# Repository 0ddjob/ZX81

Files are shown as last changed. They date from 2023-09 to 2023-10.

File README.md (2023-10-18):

# ZX81 Projects

## [ZX81 RAM Upgrade](RAM_Upgrade)
Simple plug-in 32KB RAM for ZX81 &amp; TS1000 using through-hole SRAM.  Expectation is that it's used with the very excellent [vLA81](https://www.vretrodesign.com/products/vla81-zx81-ula-replacement).<br>

{Fri 15-Sept-2023}<br>
Sent board prototype for fabrication<br>

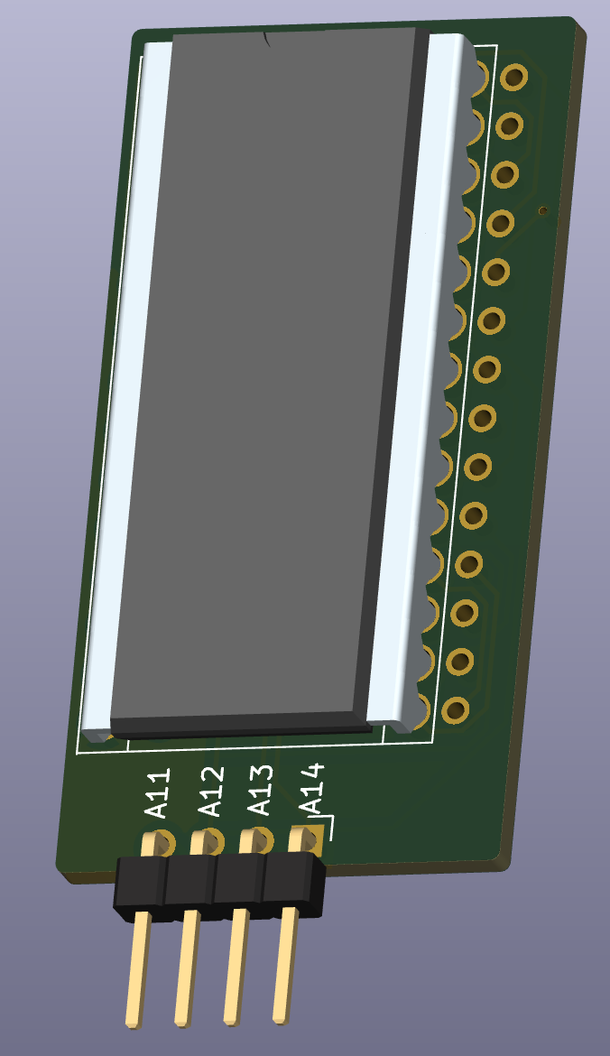
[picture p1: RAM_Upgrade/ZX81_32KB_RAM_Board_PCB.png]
PCB


## [ZX81 Centronics Interface](Centronics)
Redrawn from the original c't magazine schematic.<br>
{Sat 16-Sept-2023}<br>
Work in progress

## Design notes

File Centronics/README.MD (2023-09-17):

# ZX81 Centronics Interface

Recreating a DIY centronics interface from German computer magazine c't.<br>

Google [auto-translation](ZX81_Centronics_Interface_p1.jpg) of the German.

[Redrawn schematic](ZX81_Centronics.pdf)

{17-Sept-2023}:<br>
Work in progress ... <br>
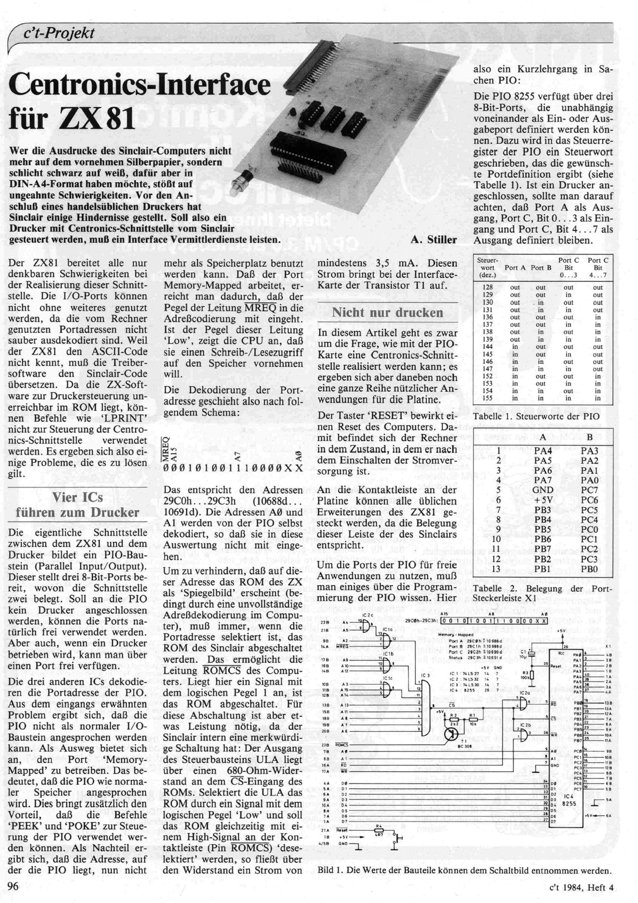
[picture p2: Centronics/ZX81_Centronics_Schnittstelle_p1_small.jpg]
CT_mag1


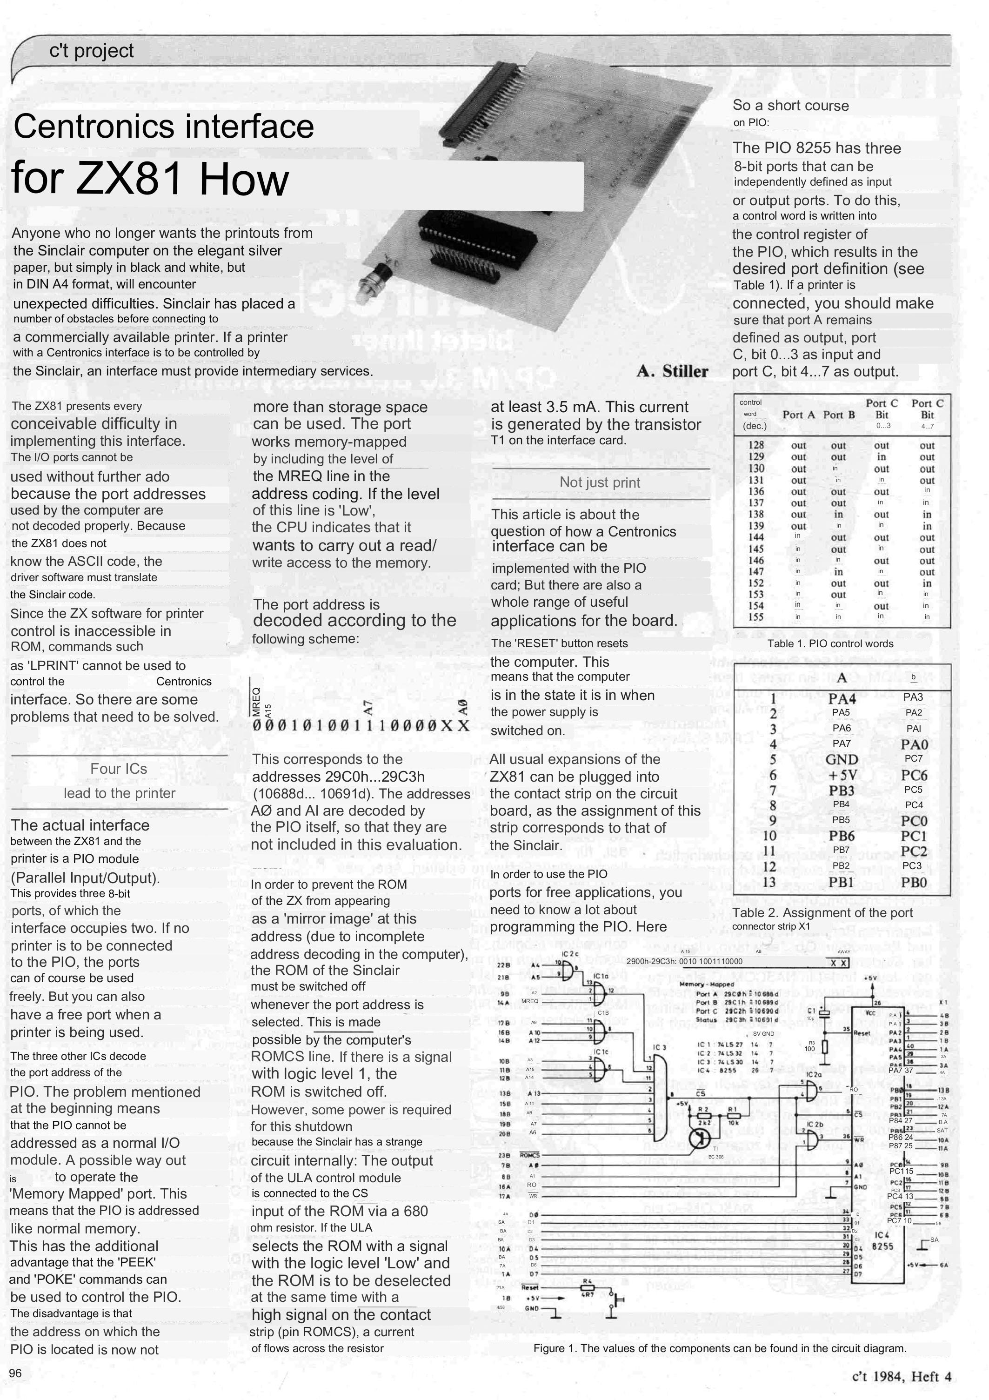
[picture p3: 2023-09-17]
Centronics/ZX81_Centronics_Interface_p1.jpg

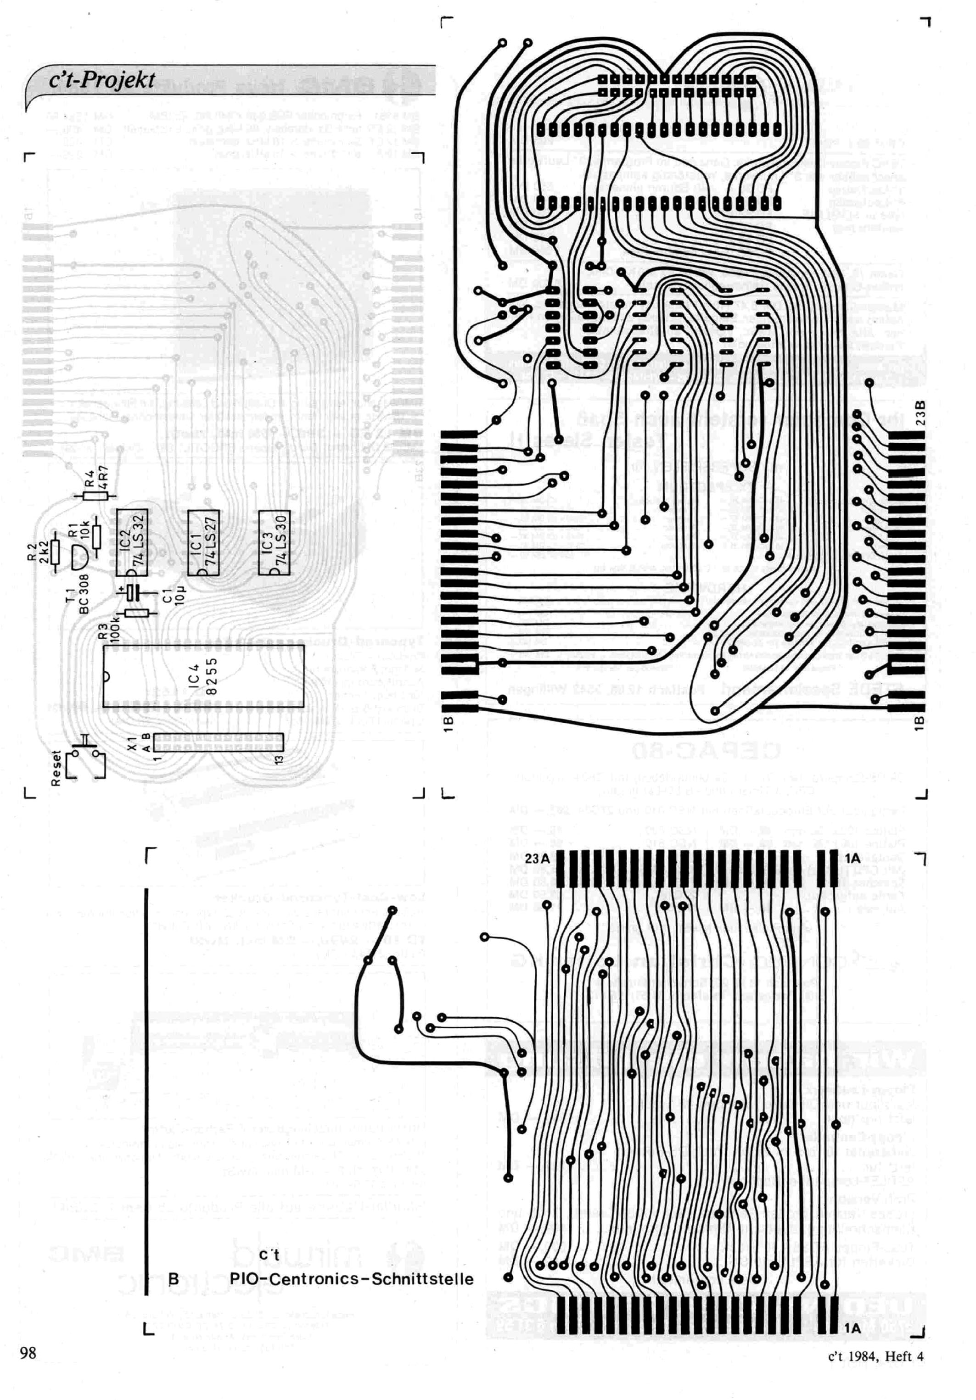
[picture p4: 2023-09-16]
Centronics/ZX81_Centronics_Schnittstelle_p2.jpg

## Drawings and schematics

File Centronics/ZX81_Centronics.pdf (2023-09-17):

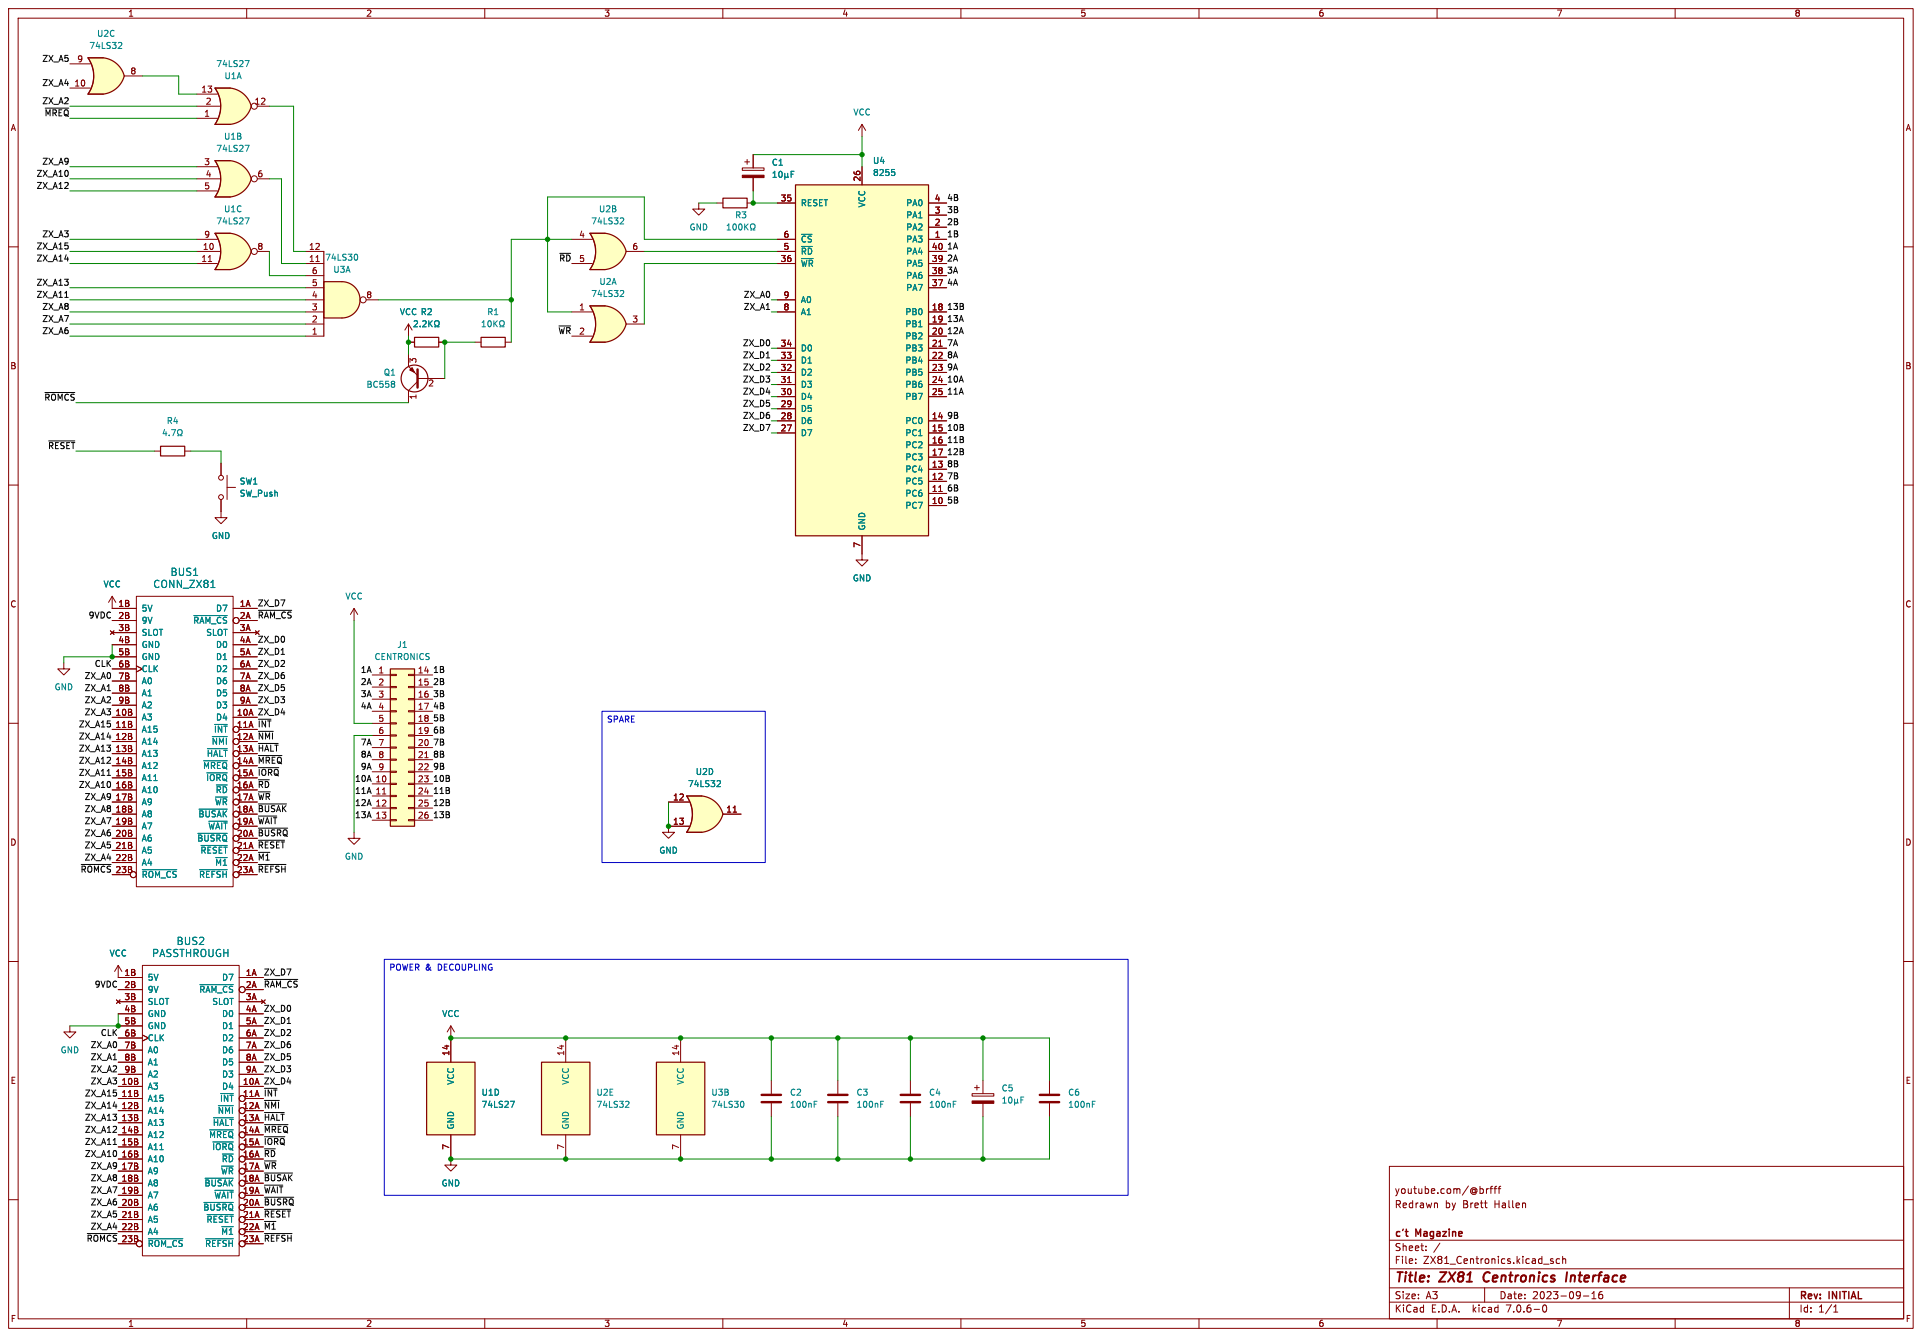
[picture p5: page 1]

ZX_D2 ZX_D1 ZX_D6 ZX_D4 ~{IORQ} ~{RD} ~{WR} ~{HALT} ~{MREQ} ~{INT} ~{M1} ~{BUSRQ} ~{WAIT} ~{REFSH} ~{BUSAK} ~{RESET} ZX_D5

File: ZX81_Centronics.kicad_sch Sheet: / c't Magazine Redrawn by Brett Hallen

Id: 1/1 Title: ZX81 Centronics Interface

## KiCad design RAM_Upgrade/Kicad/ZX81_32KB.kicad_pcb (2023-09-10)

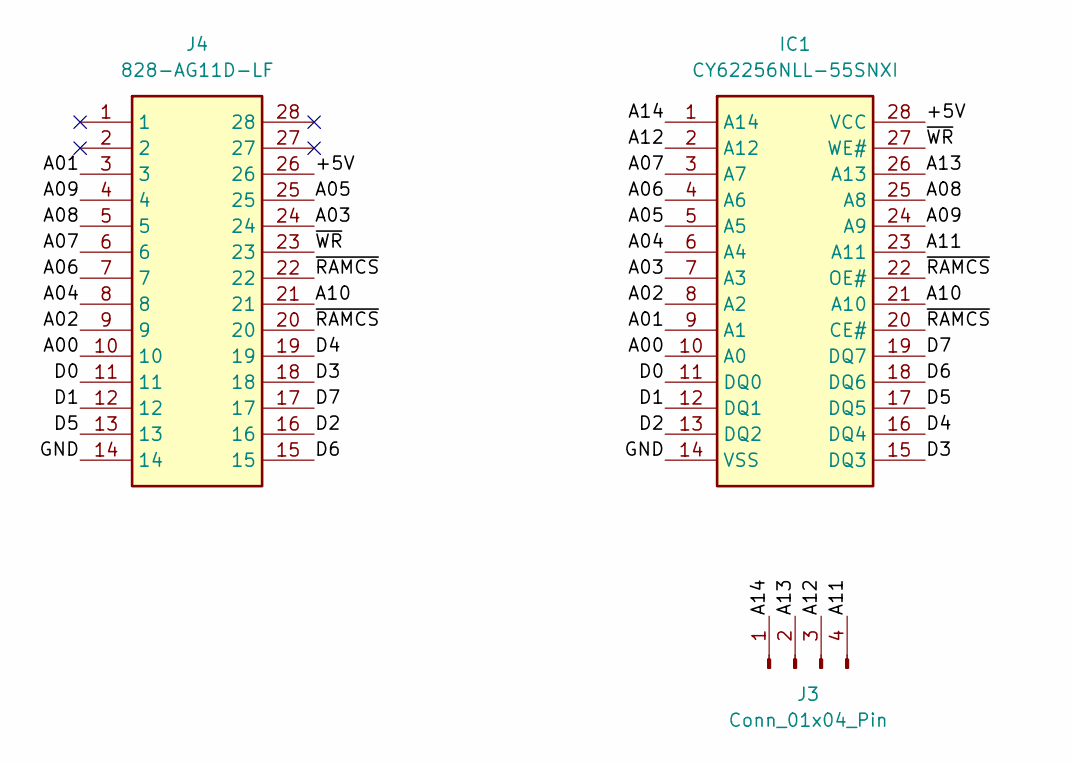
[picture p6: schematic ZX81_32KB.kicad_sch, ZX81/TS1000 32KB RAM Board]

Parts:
IC1: CY62256NLL-55SNXI; DIP1587W140P254L3632H381Q28N; Mouser Part Number 913-AS6C62256-55PCN
J3: Conn_01x04_Pin; PinHeader_1x04_P2.54mm_Horizontal
J4: 828-AG11D-LF; 828AG11DLF; Mouser Part Number 571-2-1571586-9

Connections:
/+5V: IC1.28 (VCC), J4.26
/A00: IC1.10 (A0), J4.10
/A01: IC1.9 (A1), J4.3
/A02: IC1.8 (A2), J4.9
/A03: IC1.7 (A3), J4.24
/A04: IC1.6 (A4), J4.8
/A05: IC1.5 (A5), J4.25
/A06: IC1.4 (A6), J4.7
/A07: IC1.3 (A7), J4.6
/A08: IC1.25 (A8), J4.5
/A09: IC1.24 (A9), J4.4
/A10: IC1.21 (A10), J4.21
/A11: IC1.23 (A11), J3.4
/A12: IC1.2 (A12), J3.3
/A13: IC1.26 (A13), J3.2
/A14: IC1.1 (A14), J3.1
/D0: IC1.11 (DQ0), J4.11
/D1: IC1.12 (DQ1), J4.12
/D2: IC1.13 (DQ2), J4.16
/D3: IC1.15 (DQ3), J4.18
/D4: IC1.16 (DQ4), J4.19
/D5: IC1.17 (DQ5), J4.13
/D6: IC1.18 (DQ6), J4.15
/D7: IC1.19 (DQ7), J4.17
/GND: IC1.14 (VSS), J4.14
/~RAMCS: IC1.20 (CE#), IC1.22 (OE#), J4.20, J4.22
/~WR: IC1.27 (WE#), J4.23

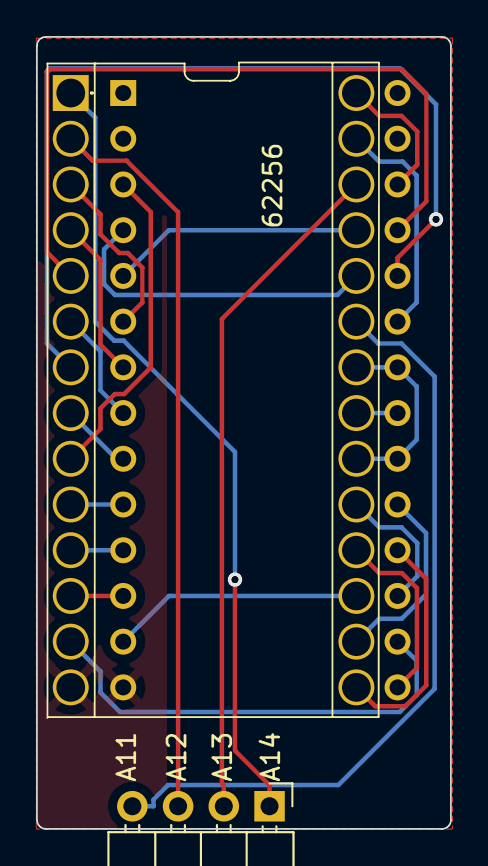
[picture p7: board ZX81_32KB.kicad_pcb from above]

Board: 2 copper layers, 23.0 x 44.0 mm, 3 parts (0 on the bottom side), 27 nets.

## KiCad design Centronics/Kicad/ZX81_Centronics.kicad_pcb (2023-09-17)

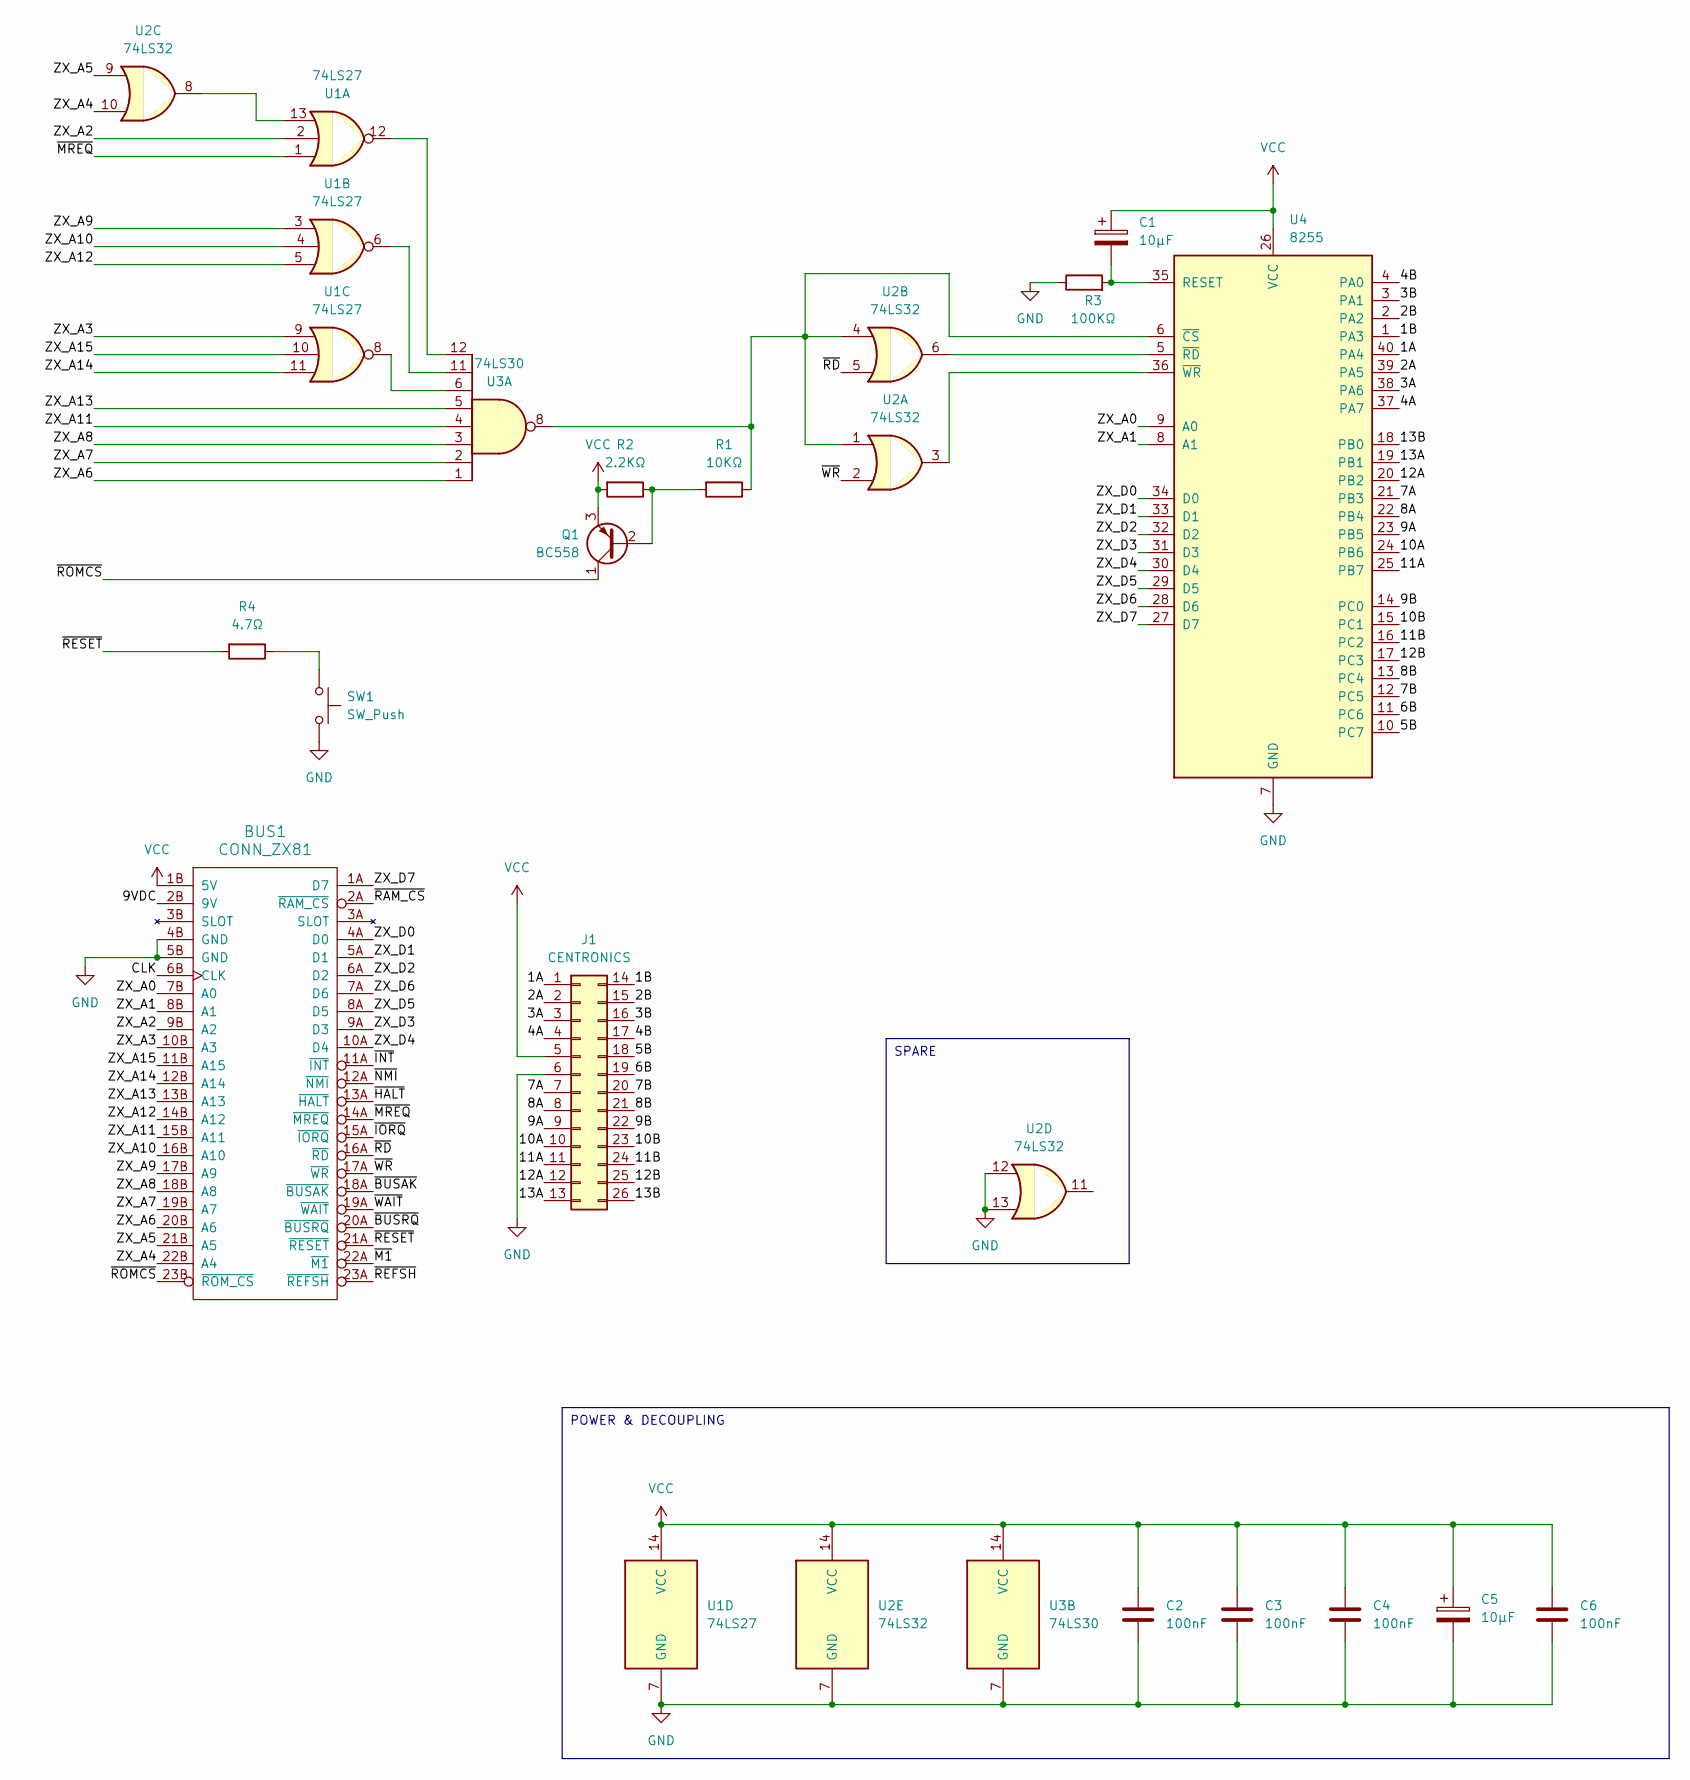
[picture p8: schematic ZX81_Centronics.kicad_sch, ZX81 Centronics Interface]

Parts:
BUS1: CONN_ZX81; ZX81_EDGE
C1, C5: 10µF; CP_Radial_D5.0mm_P2.50mm
C2, C3, C4, C6: 100nF; C_Disc_D4.3mm_W1.9mm_P5.00mm
J1: CENTRONICS; PinHeader_2x13_P2.54mm_Vertical
Q1: BC558; TO-92_Inline
R1: 10KΩ; R_Axial_DIN0207_L6.3mm_D2.5mm_P7.62mm_Horizontal
R2: 2.2KΩ; R_Axial_DIN0207_L6.3mm_D2.5mm_P7.62mm_Horizontal
R3: 100KΩ; R_Axial_DIN0207_L6.3mm_D2.5mm_P7.62mm_Horizontal
R4: 4.7Ω; R_Axial_DIN0207_L6.3mm_D2.5mm_P7.62mm_Horizontal
SW1: SW_Push; SW_PUSH_6mm_H4.3mm
U1: 74LS27; DIP-14_W7.62mm
U2: 74LS32; DIP-14_W7.62mm
U3: 74LS30; DIP-14_W7.62mm
U4: 8255; DIP-40_W15.24mm

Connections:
/1A: J1.1, U4.40 (PA4)
/1B: J1.14, U4.1 (PA3)
/2A: J1.2, U4.39 (PA5)
/2B: J1.15, U4.2 (PA2)
/3A: J1.3, U4.38 (PA6)
/3B: J1.16, U4.3 (PA1)
/4A: J1.4, U4.37 (PA7)
/4B: J1.17, U4.4 (PA0)
/5B: J1.18, U4.10 (PC7)
/6B: J1.19, U4.11 (PC6)
/7A: J1.7, U4.21 (PB3)
/7B: J1.20, U4.12 (PC5)
/8A: J1.8, U4.22 (PB4)
/8B: J1.21, U4.13 (PC4)
/9A: J1.9, U4.23 (PB5)
/9B: J1.22, U4.14 (PC0)
/9VDC: BUS1.2B (9V)
/10A: J1.10, U4.24 (PB6)
/10B: J1.23, U4.15 (PC1)
/11A: J1.11, U4.25 (PB7)
/11B: J1.24, U4.16 (PC2)
/12A: J1.12, U4.20 (PB2)
/12B: J1.25, U4.17 (PC3)
/13A: J1.13, U4.19 (PB1)
/13B: J1.26, U4.18 (PB0)
/CLK: BUS1.6B (CLK)
/ZX_A0: BUS1.7B (A0), U4.9 (A0)
/ZX_A1: BUS1.8B (A1), U4.8 (A1)
/ZX_A2: BUS1.9B (A2), U1.2
/ZX_A3: BUS1.10B (A3), U1.9
/ZX_A4: BUS1.22B (A4), U2.10
/ZX_A5: BUS1.21B (A5), U2.9
/ZX_A6: BUS1.20B (A6), U3.1
/ZX_A7: BUS1.19B (A7), U3.2
/ZX_A8: BUS1.18B (A8), U3.3
/ZX_A9: BUS1.17B (A9), U1.3
/ZX_A10: BUS1.16B (A10), U1.4
/ZX_A11: BUS1.15B (A11), U3.4
/ZX_A12: BUS1.14B (A12), U1.5
/ZX_A13: BUS1.13B (A13), U3.5
/ZX_A14: BUS1.12B (A14), U1.11
/ZX_A15: BUS1.11B (A15), U1.10
/ZX_D0: BUS1.4A (D0), U4.34 (D0)
/ZX_D1: BUS1.5A (D1), U4.33 (D1)
/ZX_D2: BUS1.6A (D2), U4.32 (D2)
/ZX_D3: BUS1.9A (D3), U4.31 (D3)
/ZX_D4: BUS1.10A (D4), U4.30 (D4)
/ZX_D5: BUS1.8A (D5), U4.29 (D5)
/ZX_D6: BUS1.7A (D6), U4.28 (D6)
/ZX_D7: BUS1.1A (D7), U4.27 (D7)
/~BUSAK: BUS1.18A (~BUSAK)
/~BUSRQ: BUS1.20A (~BUSRQ)
/~HALT: BUS1.13A (~HALT)
/~INT: BUS1.11A (~INT)
/~IORQ: BUS1.15A (~IORQ)
/~M1: BUS1.22A (~M1)
/~MREQ: BUS1.14A (~MREQ), U1.1
/~NMI: BUS1.12A (~NMI)
/~RAM_CS: BUS1.2A (~RAM_CS)
/~RD: BUS1.16A (~RD), U2.5
/~REFSH: BUS1.23A (~REFSH)
/~RESET: BUS1.21A (~RESET), R4.2
/~ROMCS: BUS1.23B (~ROM_CS), Q1.1 (C)
/~WAIT: BUS1.19A (~WAIT)
/~WR: BUS1.17A (~WR), U2.2
GND: BUS1.4B (GND), BUS1.5B (GND), C2.2, C3.2, C4.2, C5.2, C6.2, J1.6, R3.1, SW1.2, U1.7 (GND), U2.7 (GND), U2.12, U2.13, U3.7 (GND), U4.7 (GND)
unnamed: Q1.2 (B), R1.2, R2.1
unnamed: R4.1, SW1.1
unnamed: U1.6, U3.11
unnamed: U1.8, U3.6
unnamed: U1.12, U3.12
unnamed: U1.13, U2.8
unnamed: C1.2, R3.2, U4.35 (RESET)
unnamed: R1.1, U2.1, U2.4, U3.8, U4.6 (~CS)
unnamed: U2.6, U4.5 (~RD)
unnamed: U2.3, U4.36 (~WR)
VCC: BUS1.1B (5V), C1.1, C2.1, C3.1, C4.1, C5.1, C6.1, J1.5, Q1.3 (E), R2.2, U1.14 (VCC), U2.14 (VCC), U3.14 (VCC), U4.26 (VCC)

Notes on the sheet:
SPARE
POWER & DECOUPLING

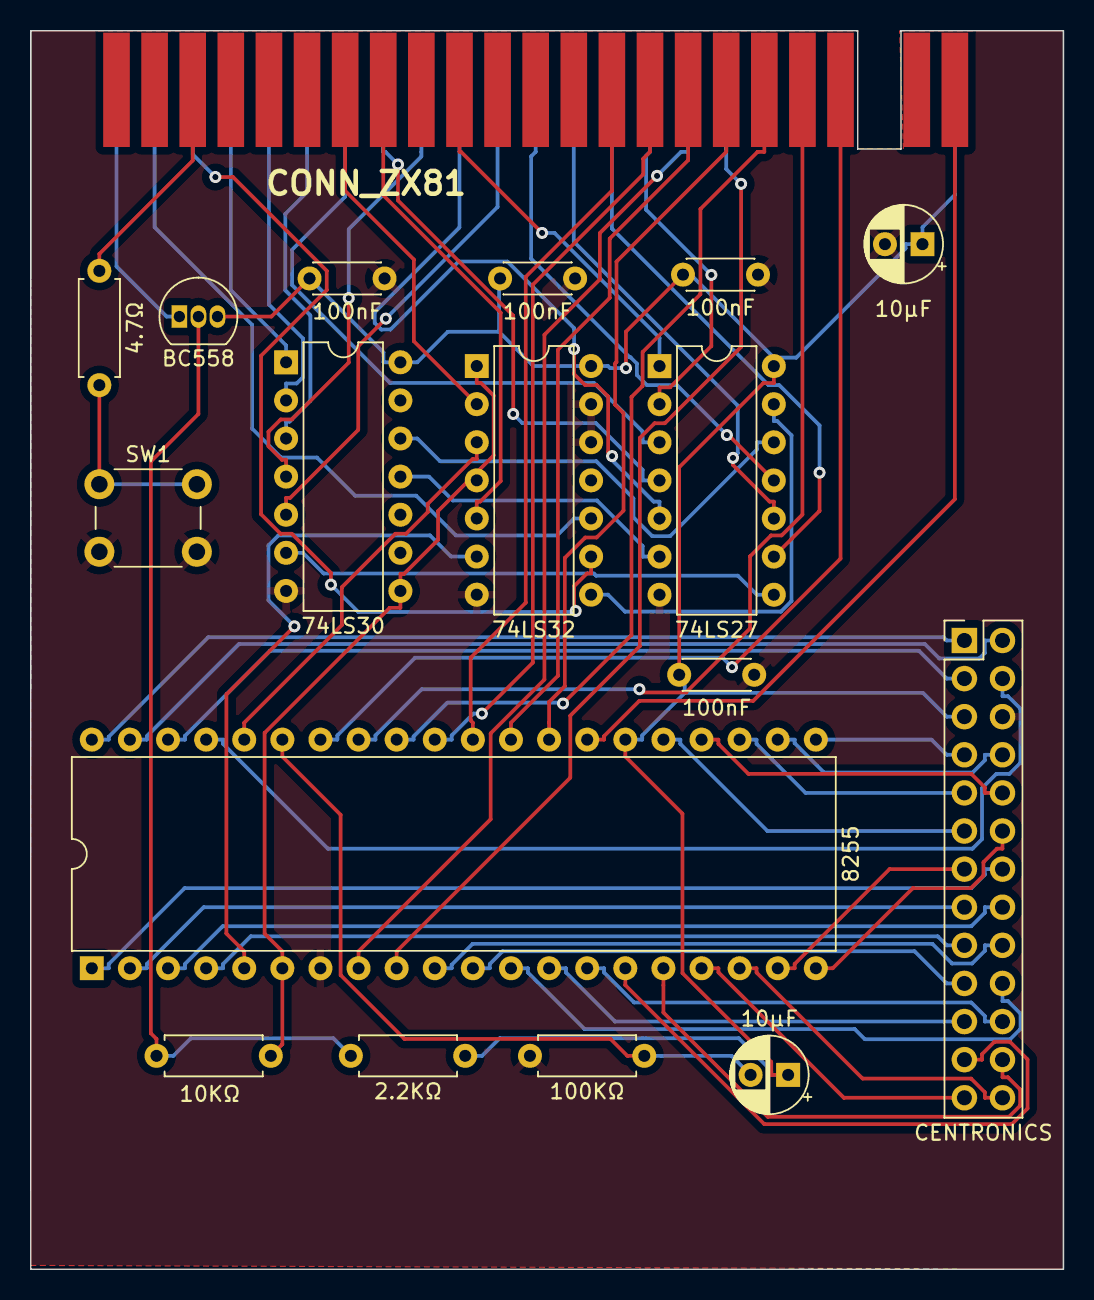
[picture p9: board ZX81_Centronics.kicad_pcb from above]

Board: 2 copper layers, 68.8 x 82.5 mm, 18 parts (0 on the bottom side), 65 nets.

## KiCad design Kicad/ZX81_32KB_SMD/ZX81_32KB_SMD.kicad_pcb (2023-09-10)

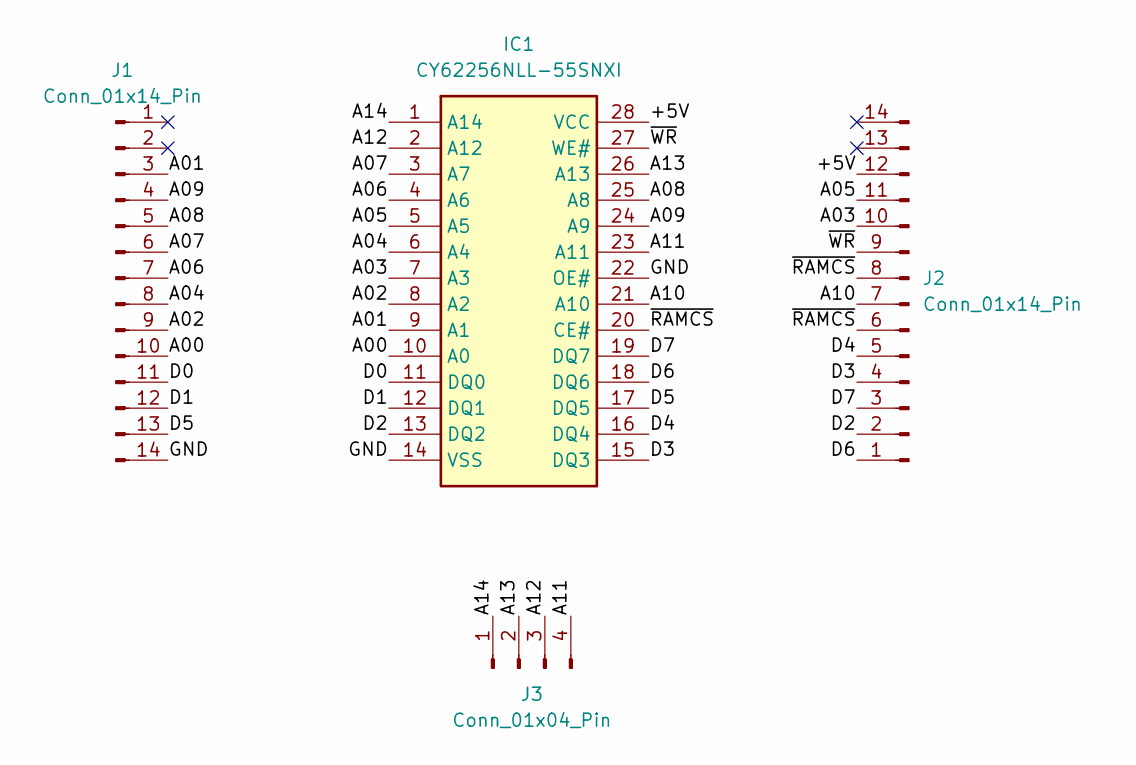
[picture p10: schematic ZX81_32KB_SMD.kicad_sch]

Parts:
IC1: CY62256NLL-55SNXI; DIP1587W140P254L3632H381Q28N; Mouser Part Number 913-AS6C62256-55PCN
J1, J2: Conn_01x14_Pin; PinHeader_1x14_P2.54mm_Vertical
J3: Conn_01x04_Pin; PinHeader_1x04_P2.54mm_Horizontal

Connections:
/+5V: IC1.28 (VCC), J2.12
/A00: IC1.10 (A0), J1.10
/A01: IC1.9 (A1), J1.3
/A02: IC1.8 (A2), J1.9
/A03: IC1.7 (A3), J2.10
/A04: IC1.6 (A4), J1.8
/A05: IC1.5 (A5), J2.11
/A06: IC1.4 (A6), J1.7
/A07: IC1.3 (A7), J1.6
/A08: IC1.25 (A8), J1.5
/A09: IC1.24 (A9), J1.4
/A10: IC1.21 (A10), J2.7
/A11: IC1.23 (A11), J3.4
/A12: IC1.2 (A12), J3.3
/A13: IC1.26 (A13), J3.2
/A14: IC1.1 (A14), J3.1
/D0: IC1.11 (DQ0), J1.11
/D1: IC1.12 (DQ1), J1.12
/D2: IC1.13 (DQ2), J2.2
/D3: IC1.15 (DQ3), J2.4
/D4: IC1.16 (DQ4), J2.5
/D5: IC1.17 (DQ5), J1.13
/D6: IC1.18 (DQ6), J2.1
/D7: IC1.19 (DQ7), J2.3
/GND: IC1.14 (VSS), IC1.22 (OE#), J1.14
/~RAMCS: IC1.20 (CE#), J2.6, J2.8
/~WR: IC1.27 (WE#), J2.9

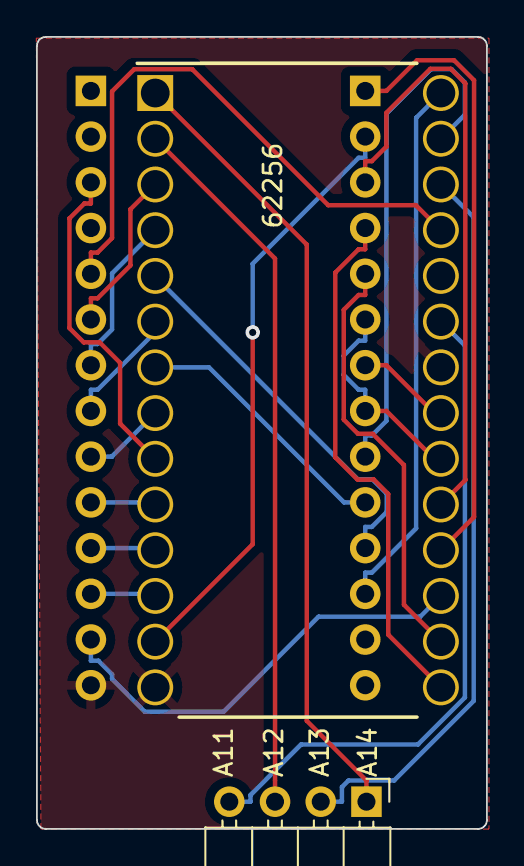
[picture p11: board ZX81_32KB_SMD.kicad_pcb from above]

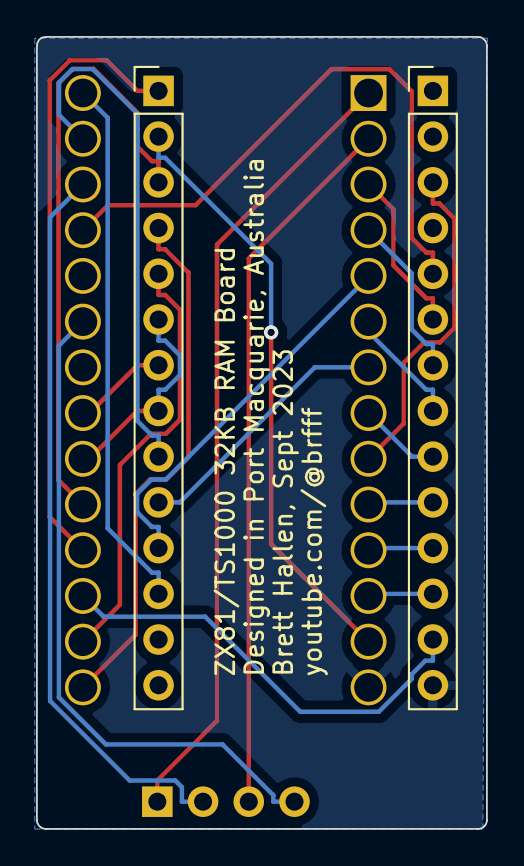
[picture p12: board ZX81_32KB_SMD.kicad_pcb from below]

Board: 2 copper layers, 25.0 x 44.0 mm, 4 parts (2 on the bottom side), 27 nets.

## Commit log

2023-09-09 Work in progress
    [ZX81_32KB_SMD.kicad_pcb, ZX81_32KB_SMD.kicad_sch]
2023-09-10 Initial version
    [ZX81_32KB.kicad_pcb, ZX81_32KB.kicad_sch]
2023-09-10 Folder move
    [ZX81_32KB.kicad_pcb, ZX81_32KB.kicad_sch]
2023-09-10 Added PCB render
2023-09-16 Adjust folders
    [ZX81_32KB.kicad_pcb, ZX81_32KB.kicad_sch]
2023-09-16 Basic schematic finished
    [ZX81_Centronics.kicad_sch]
2023-09-17 Added English auto-translation
    [ZX81_Centronics.kicad_pcb, ZX81_Centronics.kicad_sch]
2023-09-17 Updated schematic plot
    [ZX81_Centronics.kicad_pcb, ZX81_Centronics.kicad_sch]
2023-09-17 Moved schematic
2023-09-17 Generated Gerber files
    [ZX81_Centronics.kicad_pcb, ZX81_Centronics.kicad_sch]
2023-10-16 Corrected initial version
    [ZX81_32KB.kicad_pcb, ZX81_32KB.kicad_sch]
2023-10-18 Original design
    [ZX81_32KB.kicad_pcb, ZX81_32KB.kicad_sch]
2023-10-18 Revert to original design
    [ZX81_32KB.kicad_pcb, ZX81_32KB.kicad_sch]
